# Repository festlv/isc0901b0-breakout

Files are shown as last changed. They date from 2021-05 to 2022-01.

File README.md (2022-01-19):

# ISC0901B0 breakout board

ISC0901B0 is 336x256 microbolometer LWIR sensor manufactured by FLIR. 
Apparently it is being used in Tau2/Vue series camera cores, as well as many other FLIR products. 
Autoliv NV3 is also based on this sensor, and buying a second-hand, possibly damaged Autoliv NV3 module is probably the cheapest way to obtain such a sensor.

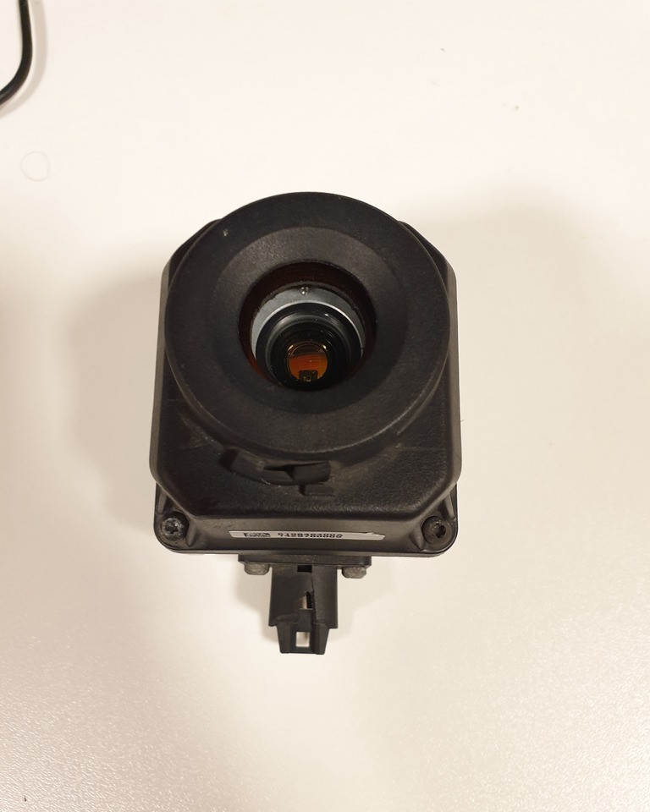
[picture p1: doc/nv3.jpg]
Autoliv NV3 front

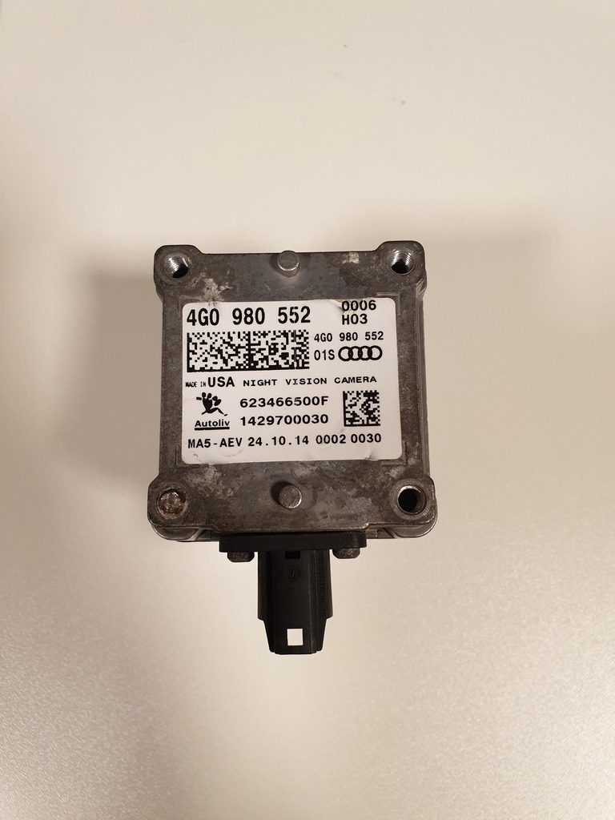
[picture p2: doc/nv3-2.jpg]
Autoliv NV3 back


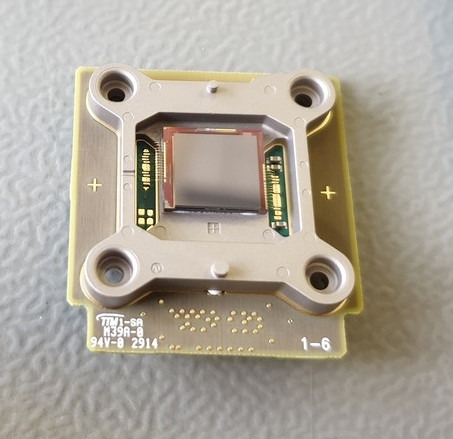
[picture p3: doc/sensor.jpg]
sensor

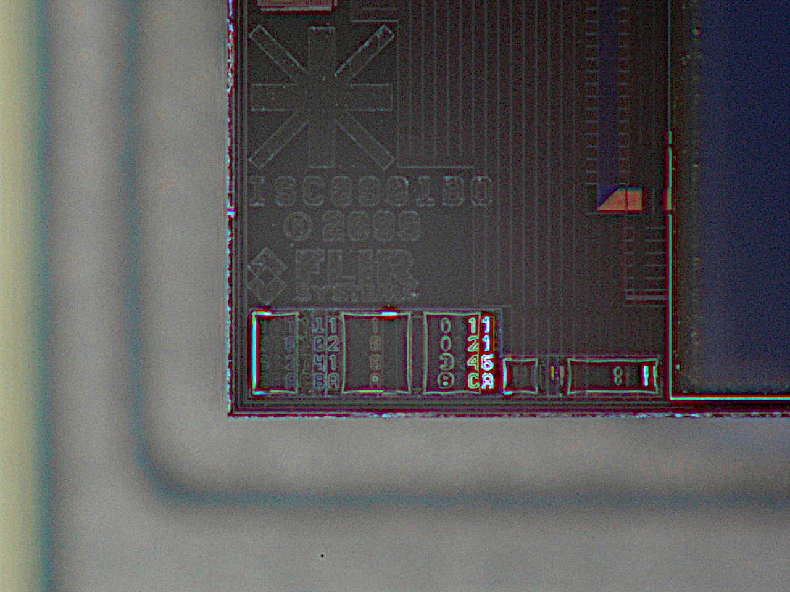
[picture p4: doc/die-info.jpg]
sensor-die

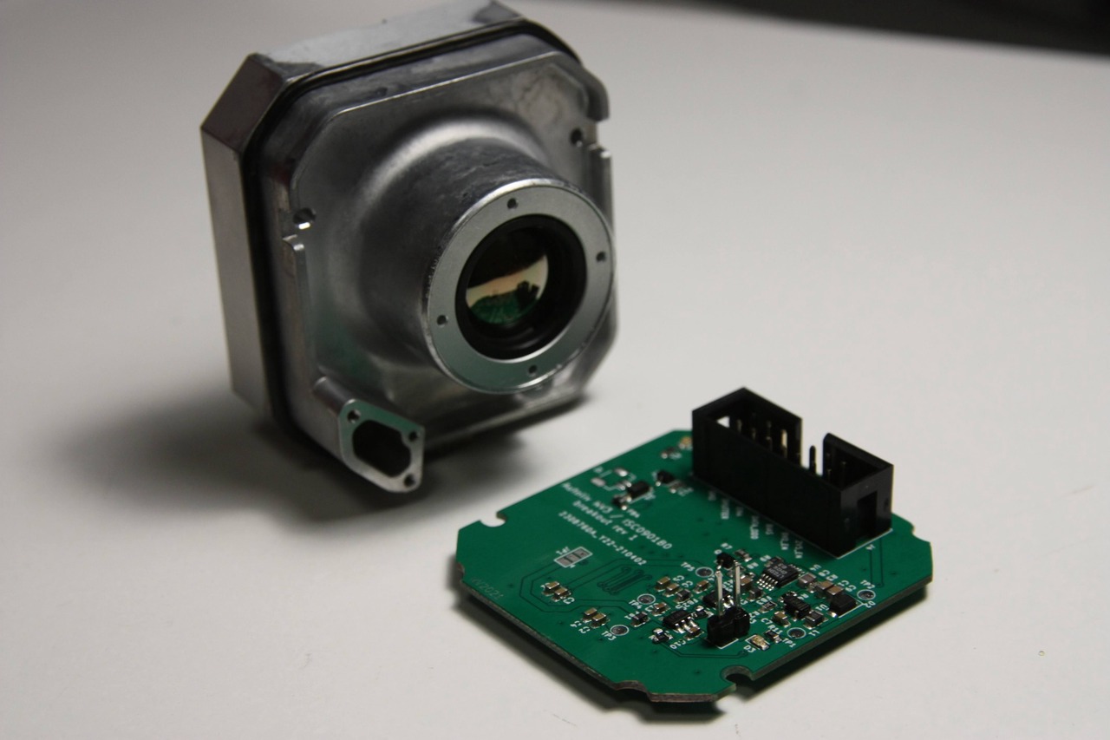
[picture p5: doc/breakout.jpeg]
breakout board


This breakout board connects directly to sensor and provides all the neccessary signals on 14-pin 2.54mm pin header (or IDC header).
It also generates the three required power rails: 2.5V for IO signals, 3.3V for core power and switchable 9/11V bias voltage.
Breakout board input voltage: 5V.
Sensor power consumption (incl. Iq of step-up convertor and LDO losses): approx 60-65mA at 5V input to breakout board.

# Sensor physical interface

All the signals described below are single ended, at VCC_IO of the sensor (2.5V in the Autoliv NV3).

**-> CLK:** clock for the sensor (nominal 73.636MHz for 60Hz). Sampling at other frequencies works, but the image is over/under exposed, as the CMD presumably configures the sensor for particular integration time.

**-> CMD:** synchronous command to sensor (output on rising edge). Bit order: MSB first. 

**-> BIAS:** synchronous bias data value to sensor. Each bias value is 7-bits long, so there is a value for each pixel. Bit order: LSB first

**-> ENA:** enable signal to sensor (?). High = sensor enabled, low = sensor disabled.

**<- DATA_0, DATA_1:** two data bits from sensor (output on falling edge, presumably sampled on rising). Each of the data lines represents a separate pixel. Bit order: LSB first.

# Startup sequence of Autoliv NV3

Measured without sensor:

1. all outputs low
2. start clk
3. 500uS delay
4. enable VCC_CORE (3.3V)
5. 15ms delay
6. enable VCC_IO (2.5V)
7. 4ms delay
8. enable VCC_BIAS (11.0V)

BIAS voltage at turn on = 11.0V

# Logical interface

After powerup sequence is finished, sensor needs to be enabled. 
Frame acquisition starts by sending a command preamble that consists of two bytes: [0x3f, 0xc0]. After that, a 20 byte sequence, of which several bytes seem to be specific to each sensor are sent.
After predetermined number of clock cycles, sensor starts responding with preamble 0x1555 on both data lines (repeating pattern of zeroes and ones).

One cycle after the sensor has started responding with preamble, bias values should be sent to sensor on the bias line: one 7-bit value for every pixel. The values are specific to each sensor: if a fixed value is sent, part of the pixels may appear to be non-responsive.
After preamble (two pixels), sensor sends the subsequent 336 pixels of image data. There is a horizontal blanking period after each line.
At the end of the readout (~256 lines), command must be sent again to initate sensor response.

The specific values for command and bias values appear to be stored in the encrypted regions of flash memory on Autoliv NV3. Further research is needed to determine if it's feasible to come up with
these values without access to flash memory contents of Autoliv NV3.

## Version history
* rev1 of this breakout board has been verified on Audi 4G0980552. 
  Observed issues: 
  * even with disabled boost converter, current path was provided by inductor.
  * outline of the PCB was slightly too large and did not fit the enclosure.
  * the 2.54mm header with just a single ground pin was very poor choice for an interface that runs at ~73MHz. It does work with ~5cm long cable though, but it's recommended to change to a different connector and add several more ground pins.

* rev2: fix first 2 problems mentioned above
* rev3: Changed the 2.54mm header with 20pin 0.5mm pitch FPC connector for better signal integrity.

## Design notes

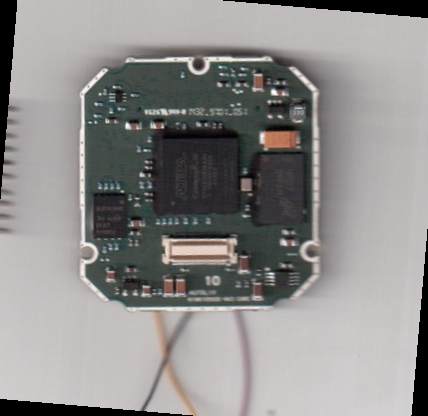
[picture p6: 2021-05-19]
pcb-outline.png

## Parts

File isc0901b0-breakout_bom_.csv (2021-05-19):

Component | Description | Part | References | Value | Footprint | Quantity Per PCB | Datasheet | MPN | Manufacturer | Config
1 | Unpolarized capacitor, small symbol | C_Small | C8 | 10pF | C_0603_1608Metric | 1 | ~
2 | Unpolarized capacitor, small symbol | C_Small | C10 C11 C13 C14 | 1uF | C_0603_1608Metric | 4 | ~
3 | Unpolarized capacitor, small symbol | C_Small | C3 C4 C6 | 0.1uF x 50V | C_0603_1608Metric | 3 | ~
4 | Unpolarized capacitor, small symbol | C_Small | C1 C2 C5 C7 C9 C12 C15 | 10uF x 25V | C_0603_1608Metric | 7 | ~ | GRT188R61E106ME13D | Murata
5 | Light emitting diode, small symbol | LED_Small | D1 D3 | LED_RED | D_0603_1608Metric | 2 | ~
6 | Diode, small symbol | D_Small | D2 D4 | MBR0520LT1 | D_SOD-123 | 2 | ~ | MBR0520LT1
7 | Ferrite bead, small symbol | Ferrite_Bead_Small | FB1 FB2 FB3 FB4 | 200R | L_0603_1608Metric | 4 | ~
8 | Generic connectable mounting pin connector, double row, 02x20, counter clockwise pin numbering scheme (similar to DIP packge numbering), script generated (kicad-library-utils/schlib/autogen/connector/) | Conn_02x20_Counter_Clockwise_MountingPin | J2 | 52991-0408 | 52991-0408 | 1 | ~ | 52991-0408
9 | Generic connector, single row, 01x02, script generated (kicad-library-utils/schlib/autogen/connector/) | Conn_01x02 | J3 | Conn_01x02 | PinHeader_1x02_P2.54mm_Vertical | 1 | ~
10 | Generic connector, single row, 01x02, script generated (kicad-library-utils/schlib/autogen/connector/) | Conn_01x02 | J5 | Conn_01x02 | JST_SH_BM02B-SRSS-TB_1x02-1MP_P1.00mm_Vertical | 1 | ~ | BM02B-SRSS-TB(LF)(SN) | JST
11 | Generic connector, double row, 02x07, odd/even pin numbering scheme (row 1 odd numbers, row 2 even numbers), script generated (kicad-library-utils/schlib/autogen/connector/) | Conn_02x07_Odd_Even | J4 | IDC_02x07 | IDC-Header_2x07_P2.54mm_Vertical | 1 | ~ | 302-S141 | On Shore Technology Inc.
12 | Inductor, small symbol | L_Small | L1 | 4.7uH | L_0805_2012Metric | 1 | ~
13 | N-MOSFET transistor, gate/source/drain | Q_NMOS_GSD | Q1 Q2 | BSS138PW,115 | SOT-323_SC-70 | 2 | ~ | BSS138PW,115
14 | Resistor, small symbol | R_Small | R1 R11 | 1K | R_0603_1608Metric | 2 | ~
15 | Resistor, small symbol | R_Small | R2 R7 R12 | 10K | R_0603_1608Metric | 3 | ~
16 | Resistor, small symbol | R_Small | R4 | 11.5K | R_0603_1608Metric | 1 | ~
17 | Resistor, small symbol | R_Small | R3 | 100K | R_0603_1608Metric | 1 | ~
18 | Resistor, small symbol | R_Small | R10 | 110K | R_0603_1608Metric | 1 | ~
19 | Resistor, small symbol | R_Small | R8 | 499K | R_0603_1608Metric | 1 | ~
20 | 4 resistor network, parallel topology | R_Pack04 | RN1 RN2 RN3 | 22R | R_Array_Concave_4x0603 | 3 | ~ | EXB-V8V220JV
21 |  | ADP151 | U3 | ADP151AUJZ-2.5-R7 | TSOT-23-5 | 1 |  | ADP151AUJZ-2.5-R7
22 |  | ADP151 | U2 | ADP151AUJZ-3.3-R7 | TSOT-23-5 | 1 |  | ADP151AUJZ-3.3-R7
23 | 200mA, Adjustable, Ultralow Noise, Ultrahigh PSRR RF Linear Regulator, MSOP-10 | LT3042xMSE | U4 | LT3042xMSE | MSOP-10-1EP_3x3mm_P0.5mm_EP1.68x1.88mm | 1 | https://www.analog.com/media/en/technical-documentation/data-sheets/3042fb.pdf | LT3042EMSE#PBF
24 | Synchronous Boost Regulator, Adjustable Output up to 28V, 250 mA Switch Current Limit, SOT-23-5 | TPS61041DBV | U1 | TPS61041DBV | SOT-23-5 | 1 | http://www.ti.com/lit/ds/symlink/tps61040.pdf | TPS61041DBV
Component Groups: | 26
Component Count: | 50
Fitted Components: | 46
Number of PCBs: | 1
Total components: | 46
Schematic Version:
Schematic Date:
PCB Variant: | ['default']
BoM Date: | pirmdiena, 2021. gada 19. aprīlis, 15:43:23
Schematic Source: | ics0901b0-breakout.sch
KiCad Version: | Eeschema 5.1.9-73d0e3b20d~88~ubuntu20.04.1

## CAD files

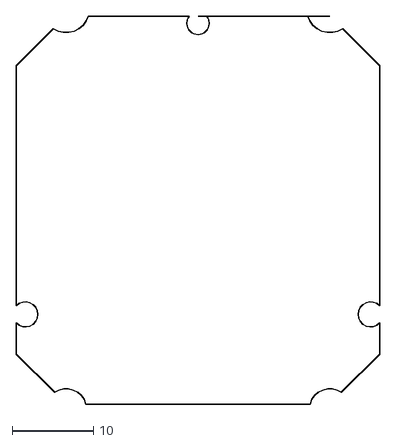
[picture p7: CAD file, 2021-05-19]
pcb-outline (1).dxf
44.9 x 47.9

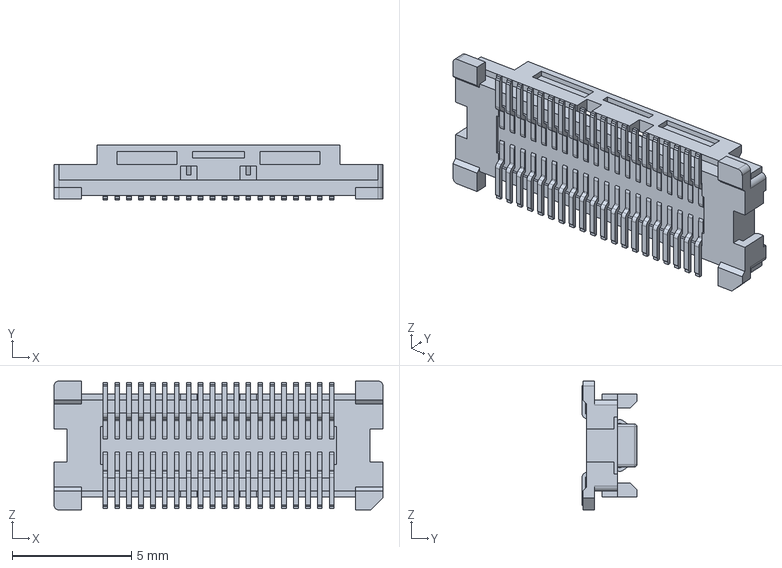
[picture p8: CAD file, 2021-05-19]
529910408.stp
13.8 x 2.30 x 5.40 mm

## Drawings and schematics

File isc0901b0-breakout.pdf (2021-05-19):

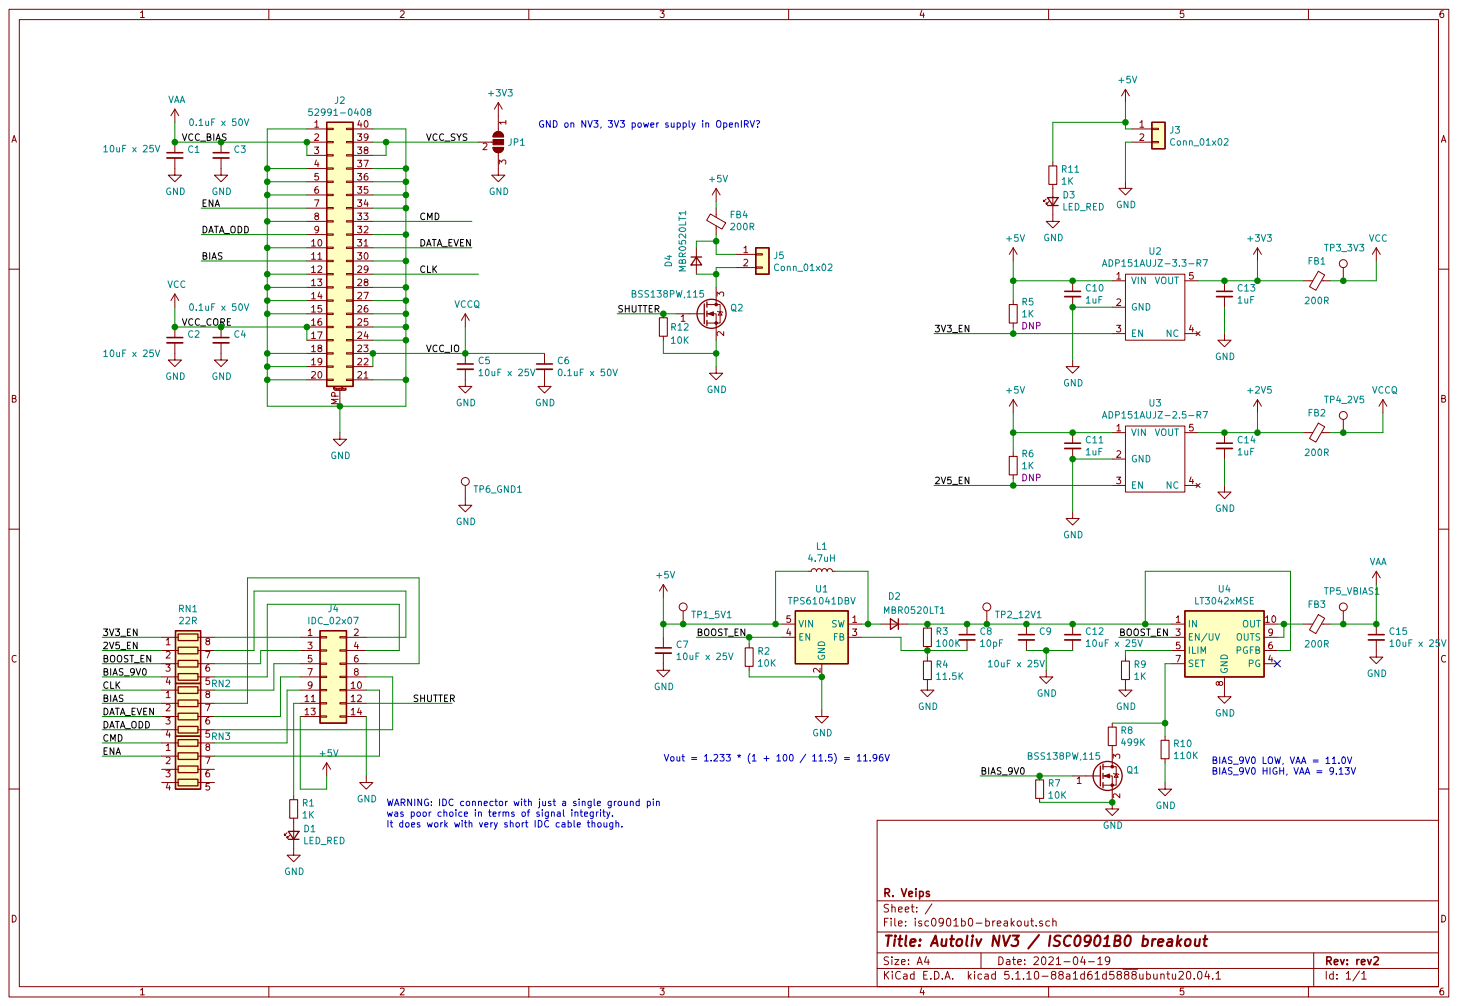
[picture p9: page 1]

GND on NV3, 3V3 power supply in OpenIRV?

5 | 36
6 | 35
7 | 34
8 | 33 32

14 | 27
15 | 26
16 | 25
17 | 24

19 | 22
20 | 21

BOOST_EN | BOOST_EN

9 | | 10
11 | | 12 14

was poor choice in terms of signal integrity.
It does work with very short IDC cable though.

Id: 1/1 Title: Autoliv NV3 / ISC0901B0 breakout File: isc0901b0-breakout.sch Sheet: / R. Veips

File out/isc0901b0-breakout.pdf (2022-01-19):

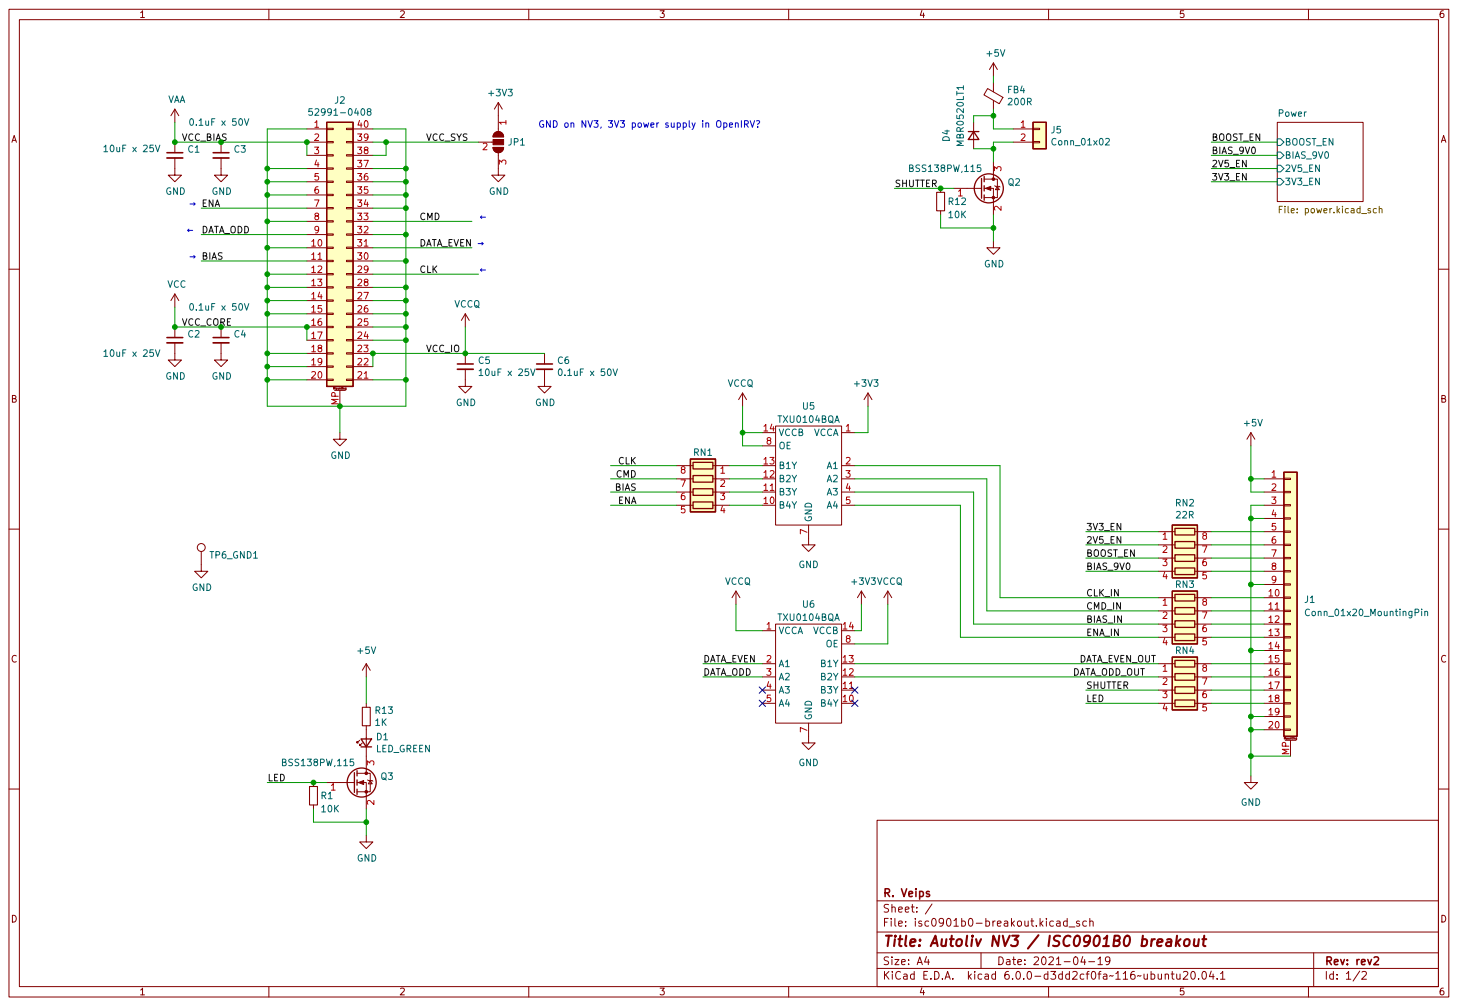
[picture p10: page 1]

8 | Mounting 1 | 33 32

GND on NV3, 3V3 power supply in OpenIRV?

5 | | 36
6 | | 35
7 | | 34

14 | 27
15 | 26
16 | 25
17 | 24

19 | 22
20 | 21

1 DATA_ODD_OUT | | 16 | J1Conn_01x20_MountingPin GND

2 SHUTTER | 7 | 17

File: isc0901b0-breakout.kicad_sch Sheet: / R. Veips

Id: 1/2 Title: Autoliv NV3 / ISC0901B0 breakout

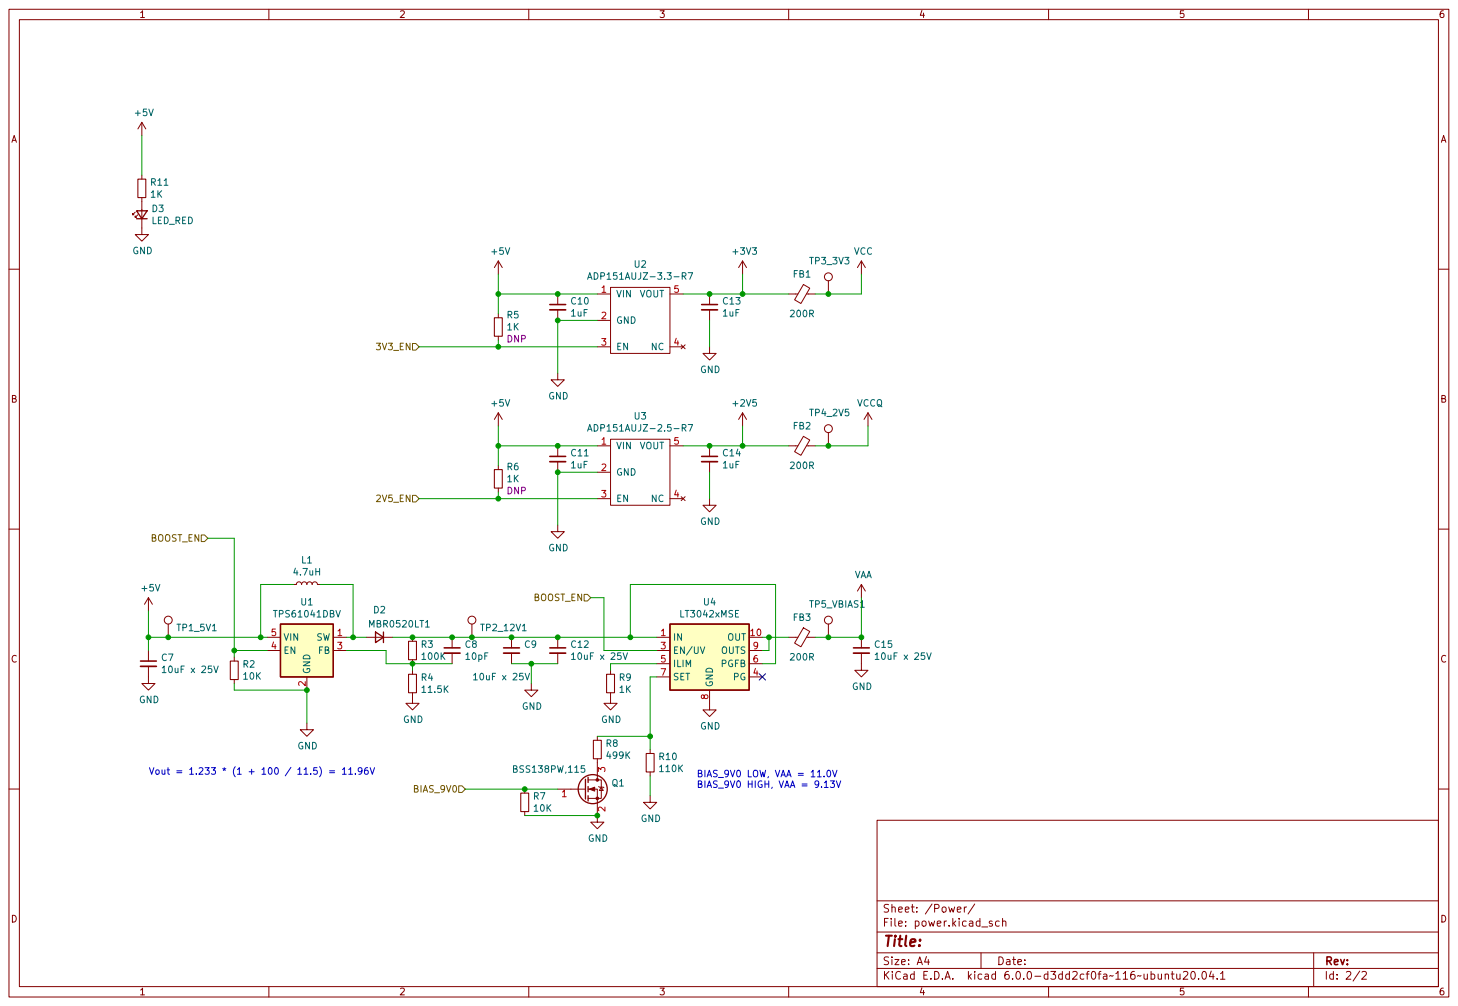
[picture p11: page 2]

File: power.kicad_sch Sheet: /Power/
Id: 2/2 Title:

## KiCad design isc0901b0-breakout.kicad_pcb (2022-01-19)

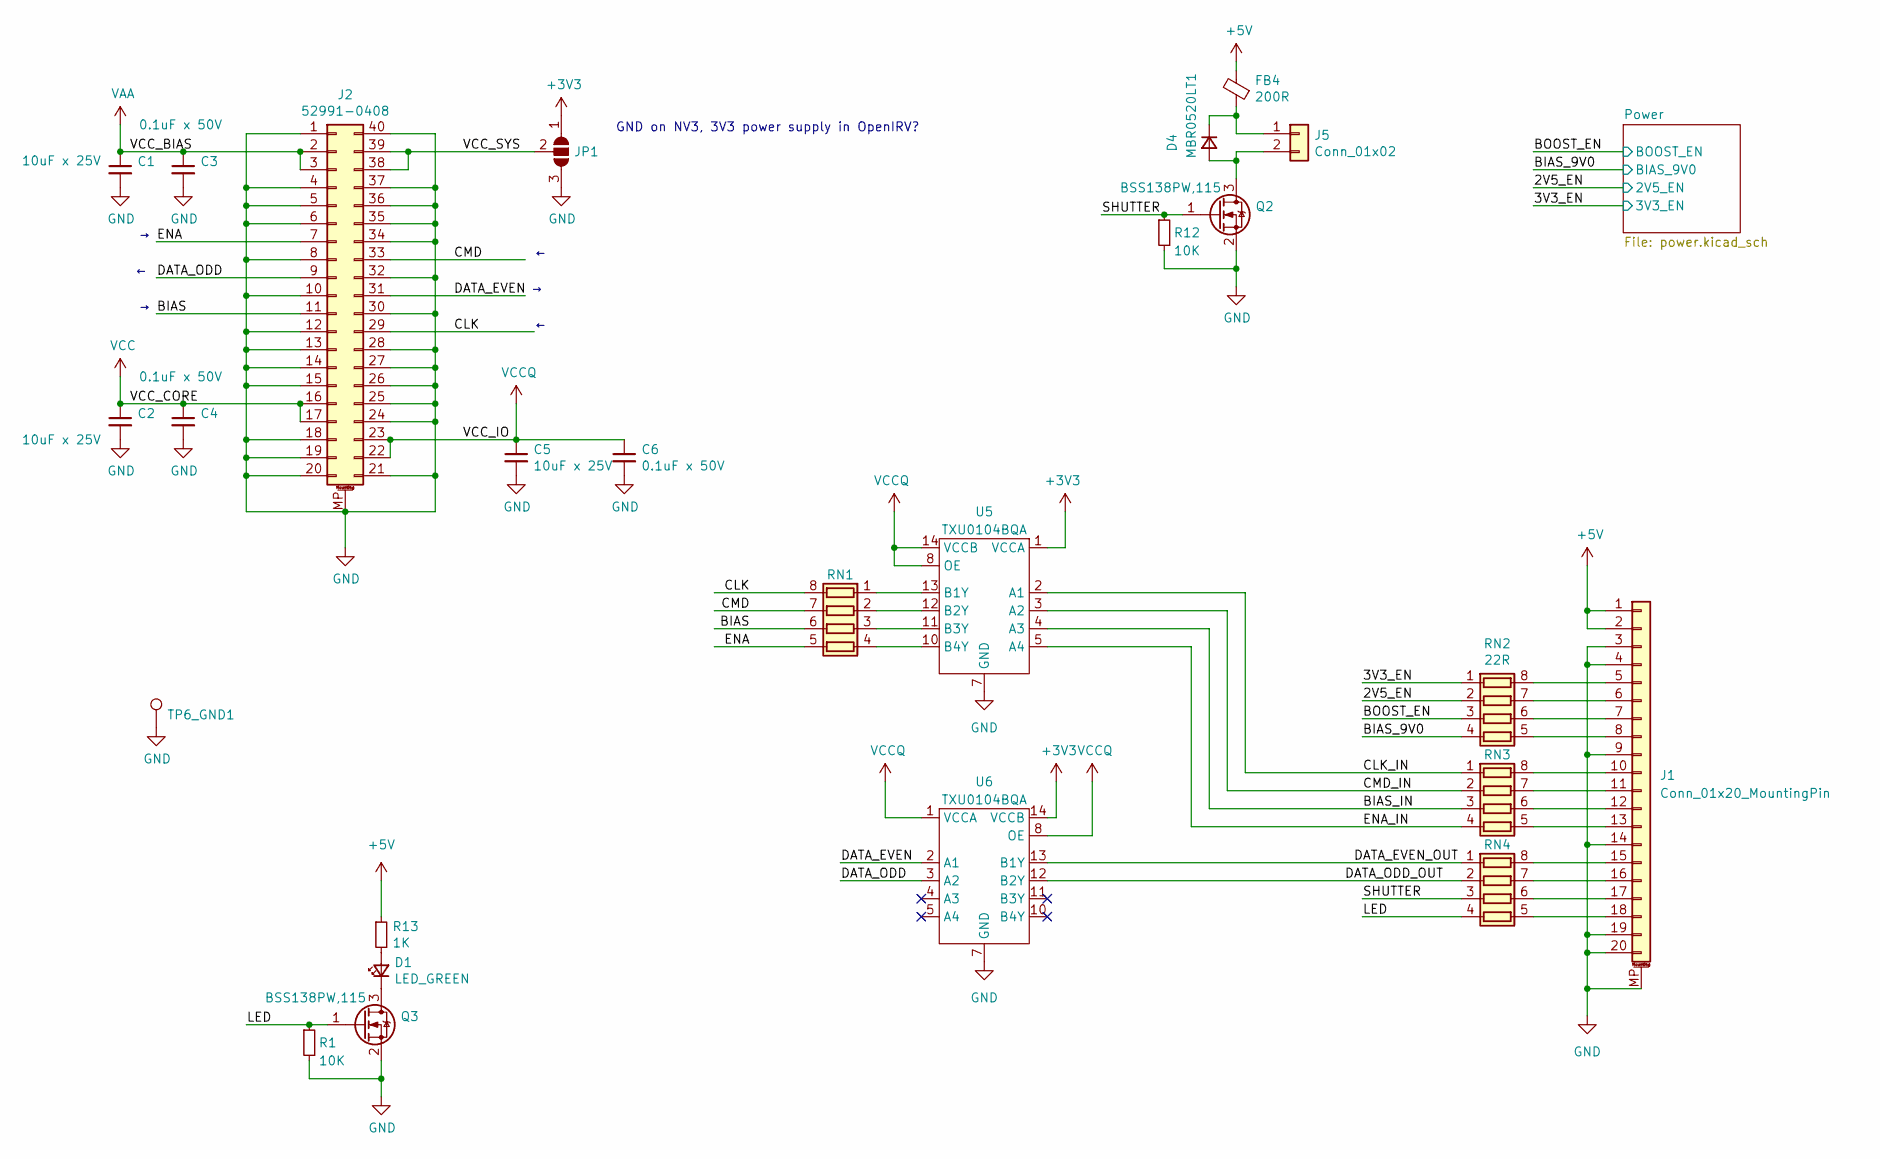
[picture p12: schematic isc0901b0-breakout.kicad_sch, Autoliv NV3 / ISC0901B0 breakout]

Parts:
C1, C2, C5: 10uF x 25V; C_0603_1608Metric; MPN GRT188R61E106ME13D
C3, C4, C6: 0.1uF x 50V; C_0603_1608Metric
D1: LED_GREEN; D_0603_1608Metric
D4: MBR0520LT1; D_SOD-123; MPN MBR0520LT1
FB4: 200R; L_0603_1608Metric
J1: Conn_01x20_MountingPin; X05C2020TZ; MPN X05C2020TZ
J2: 52991-0408; MPN 52991-0408
J5: Conn_01x02; JST_SH_BM02B-SRSS-TB_1x02-1MP_P1.00mm_Vertical; MPN BM02B-SRSS-TB(LF)(SN)
JP1: SolderJumper_3_Open; SolderJumper-3_P1.3mm_Open_Pad1.0x1.5mm
Q2, Q3: BSS138PW,115; SOT-323_SC-70; MPN BSS138PW,115
R1, R12: 10K; R_0603_1608Metric
R13: 1K; R_0603_1608Metric
RN1, RN2, RN3, RN4: 22R; R_Array_Concave_4x0603; MPN EXB-V8V220JV
TP6_GND1: TestPoint; TestPoint_Pad_D1.5mm
U5, U6: TXU0104BQA; TI_WFNQ-14_BQA; MPN TXU0104BQAR

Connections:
+3V3: JP1.1 (A), U5.1 (VCCA), U6.14 (VCCB); also elsewhere on the board
+5V: FB4.2, J1.1, J1.2, R13.1; also elsewhere on the board
/2V5_EN: RN2.2 (R2.1); also elsewhere on the board
/3V3_EN: RN2.1 (R1.1); also elsewhere on the board
/BIAS: J2.11, RN1.6 (R3.2)
/BIAS_9V0: RN2.4 (R4.1); also elsewhere on the board
/BIAS_IN: RN3.3 (R3.1), U5.4 (A3)
/BOOST_EN: RN2.3 (R3.1); also elsewhere on the board
/CLK: J2.29, RN1.8 (R1.2)
/CLK_IN: RN3.1 (R1.1), U5.2 (A1)
/CMD: J2.33, RN1.7 (R2.2)
/CMD_IN: RN3.2 (R2.1), U5.3 (A2)
/DATA_EVEN: J2.31, U6.2 (A1)
/DATA_EVEN_OUT: RN4.1 (R1.1), U6.13 (B1Y)
/DATA_ODD: J2.9, U6.3 (A2)
/DATA_ODD_OUT: RN4.2 (R2.1), U6.12 (B2Y)
/ENA: J2.7, RN1.5 (R4.2)
/ENA_IN: RN3.4 (R4.1), U5.5 (A4)
/LED: Q3.1 (G), R1.1, RN4.4 (R4.1)
/SHUTTER: Q2.1 (G), R12.1, RN4.3 (R3.1)
/VCC_SYS: J2.38, J2.39, JP1.2 (C)
GND: C1.2, C2.2, C3.2, C4.2, C5.2, C6.2, J1.3, J1.4, J1.9, J1.14, J1.19, J1.20, J1.MP (MountPin), J2.1, J2.4, J2.5, J2.6, J2.8, J2.10, J2.12, J2.13, J2.14, J2.15, J2.18, J2.19, J2.20, J2.21, J2.24, J2.25, J2.26, J2.27, J2.28, J2.30, J2.32, J2.34, J2.35, J2.36, J2.37, J2.40, J2.MP (MountPin), JP1.3 (B), Q2.2 (S), Q3.2 (S), R1.2, R12.2, TP6_GND1.1, U5.7 (GND), U6.7 (GND); also elsewhere on the board
unnamed: D1.1 (K), Q3.3 (D)
unnamed: D1.2 (A), R13.2
unnamed: D4.1 (K), FB4.1, J5.1
unnamed: D4.2 (A), J5.2, Q2.3 (D)
unnamed: J1.5, RN2.8 (R1.2)
unnamed: J1.6, RN2.7 (R2.2)
unnamed: J1.7, RN2.6 (R3.2)
unnamed: J1.8, RN2.5 (R4.2)
unnamed: J1.10, RN3.8 (R1.2)
unnamed: J1.11, RN3.7 (R2.2)
unnamed: J1.12, RN3.6 (R3.2)
unnamed: J1.13, RN3.5 (R4.2)
unnamed: J1.15, RN4.8 (R1.2)
unnamed: J1.16, RN4.7 (R2.2)
unnamed: J1.17, RN4.6 (R3.2)
unnamed: J1.18, RN4.5 (R4.2)
unnamed: RN1.1 (R1.1), U5.13 (B1Y)
unnamed: RN1.2 (R2.1), U5.12 (B2Y)
unnamed: RN1.3 (R3.1), U5.11 (B3Y)
unnamed: RN1.4 (R4.1), U5.10 (B4Y)
VAA: C1.1, C3.1, J2.2, J2.3; also elsewhere on the board
VCC: C2.1, C4.1, J2.16, J2.17; also elsewhere on the board
VCCQ: C5.1, C6.1, J2.22, J2.23, U5.8 (OE), U5.14 (VCCB), U6.1 (VCCA), U6.8 (OE); also elsewhere on the board

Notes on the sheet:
GND on NV3, 3V3 power supply in OpenIRV?

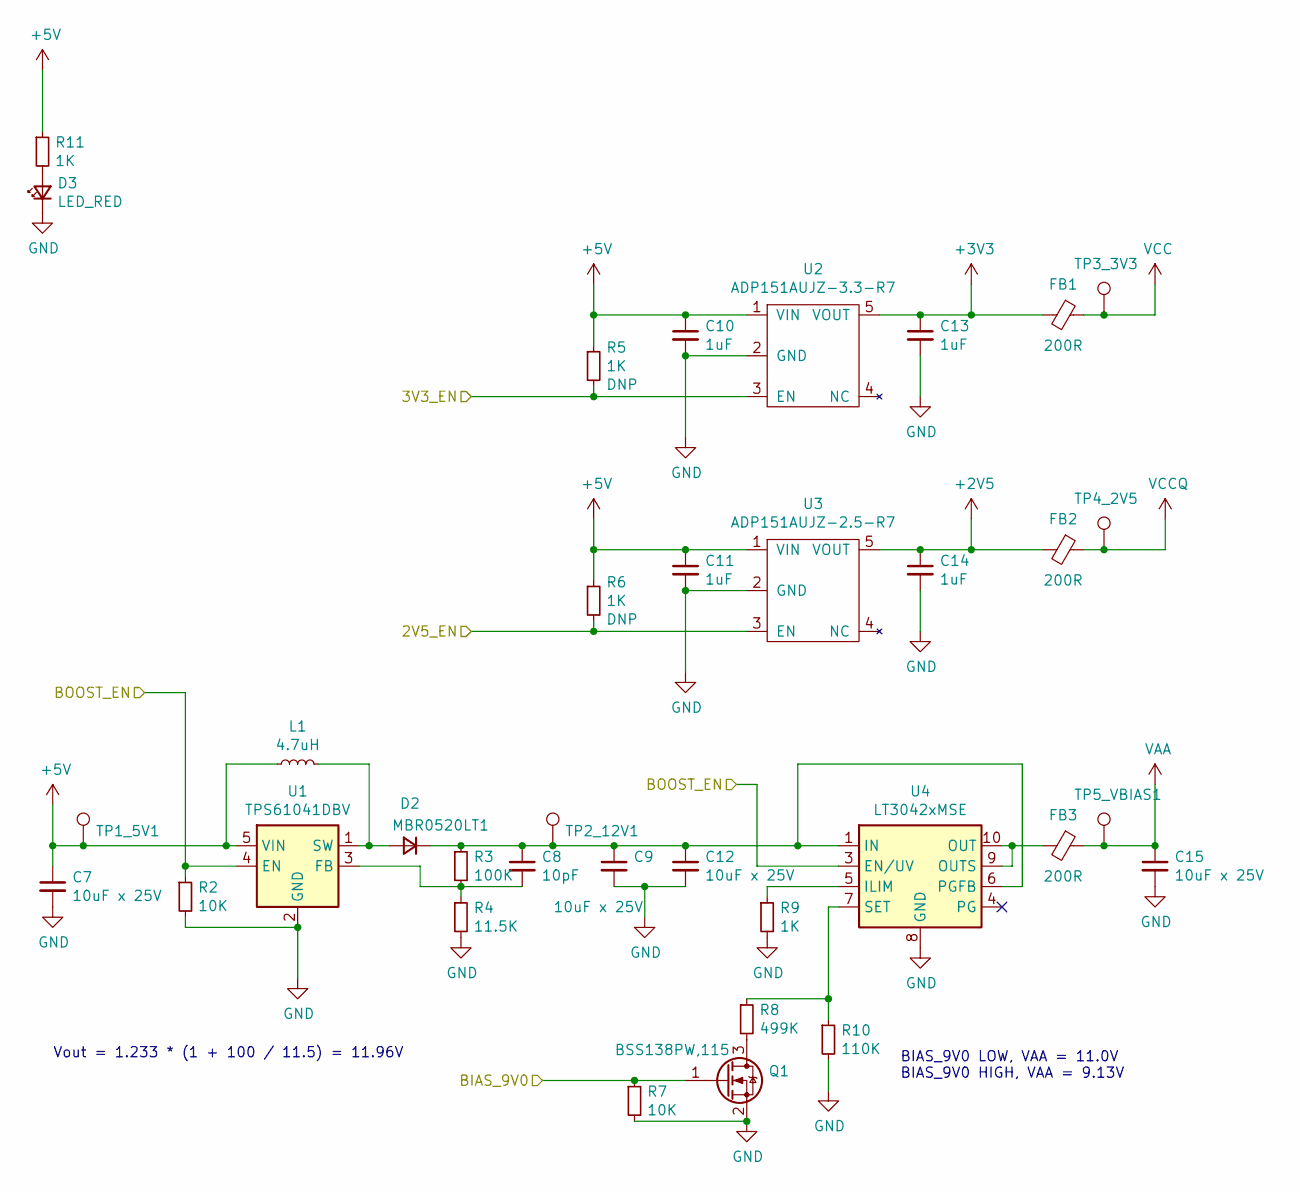
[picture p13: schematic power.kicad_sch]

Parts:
C7, C9, C12, C15: 10uF x 25V; C_0603_1608Metric; MPN GRT188R61E106ME13D
C8: 10pF; C_0603_1608Metric
C10, C11, C13, C14: 1uF; C_0603_1608Metric
D2: MBR0520LT1; D_SOD-123
D3: LED_RED; D_0603_1608Metric
FB1, FB2, FB3: 200R; L_0603_1608Metric
L1: 4.7uH; L_0805_2012Metric
Q1: BSS138PW,115; SOT-323_SC-70; MPN BSS138PW,115
R2, R7: 10K; R_0603_1608Metric
R3: 100K; R_0603_1608Metric
R4: 11.5K; R_0603_1608Metric
R5, R6, R9, R11: 1K; R_0603_1608Metric
R8: 499K; R_0603_1608Metric
R10: 110K; R_0603_1608Metric
TP1_5V1, TP2_12V1, TP3_3V3, TP4_2V5, TP5_VBIAS1: TestPoint; TestPoint_Pad_D1.5mm
U1: TPS61041DBV; SOT-23-5; MPN TPS61041DBV
U2: ADP151AUJZ-3.3-R7; TSOT-23-5; MPN ADP151AUJZ-3.3-R7
U3: ADP151AUJZ-2.5-R7; TSOT-23-5; MPN ADP151AUJZ-2.5-R7
U4: LT3042xMSE; MSOP-10-1EP_3x3mm_P0.5mm_EP1.68x1.88mm; MPN LT3042EMSE#PBF

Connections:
+2V5: C14.1, FB2.2, U3.5 (VOUT)
+3V3: C13.1, FB1.2, U2.5 (VOUT); also elsewhere on the board
+5V: C7.1, C10.1, C11.1, L1.1, R5.1, R6.1, R11.1, TP1_5V1.1, U1.5 (VIN), U2.1 (VIN), U3.1 (VIN); also elsewhere on the board
/2V5_EN: R6.2, U3.3 (EN); also elsewhere on the board
/3V3_EN: R5.2, U2.3 (EN); also elsewhere on the board
/BIAS_9V0: Q1.1 (G), R7.1; also elsewhere on the board
/BOOST_EN: R2.1, U1.4 (EN), U4.3 (EN/UV); also elsewhere on the board
GND: C7.2, C9.2, C10.2, C11.2, C12.2, C13.2, C14.2, C15.2, D3.1 (K), Q1.2 (S), R2.2, R4.2, R7.2, R9.2, R10.2, U1.2 (GND), U2.2 (GND), U3.2 (GND), U4.8 (GND), U4.11 (GND); also elsewhere on the board
unnamed: C8.2, R3.2, R4.1, U1.3 (FB)
unnamed: C8.1, C9.1, C12.1, D2.1 (K), R3.1, TP2_12V1.1, U4.1 (IN), U4.2 (IN), U4.6 (PGFB)
unnamed: D2.2 (A), L1.2, U1.1 (SW)
unnamed: D3.2 (A), R11.2
unnamed: FB3.2, U4.9 (OUTS), U4.10 (OUT)
unnamed: Q1.3 (D), R8.2
unnamed: R9.1, U4.5 (ILIM)
unnamed: R8.1, R10.1, U4.7 (SET)
VAA: C15.1, FB3.1, TP5_VBIAS1.1; also elsewhere on the board
VCC: FB1.1, TP3_3V3.1; also elsewhere on the board
VCCQ: FB2.1, TP4_2V5.1; also elsewhere on the board

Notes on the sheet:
BIAS_9V0 LOW, VAA = 11.0V BIAS_9V0 HIGH, VAA = 9.13V
Vout = 1.233 * (1 + 100 / 11.5) = 11.96V

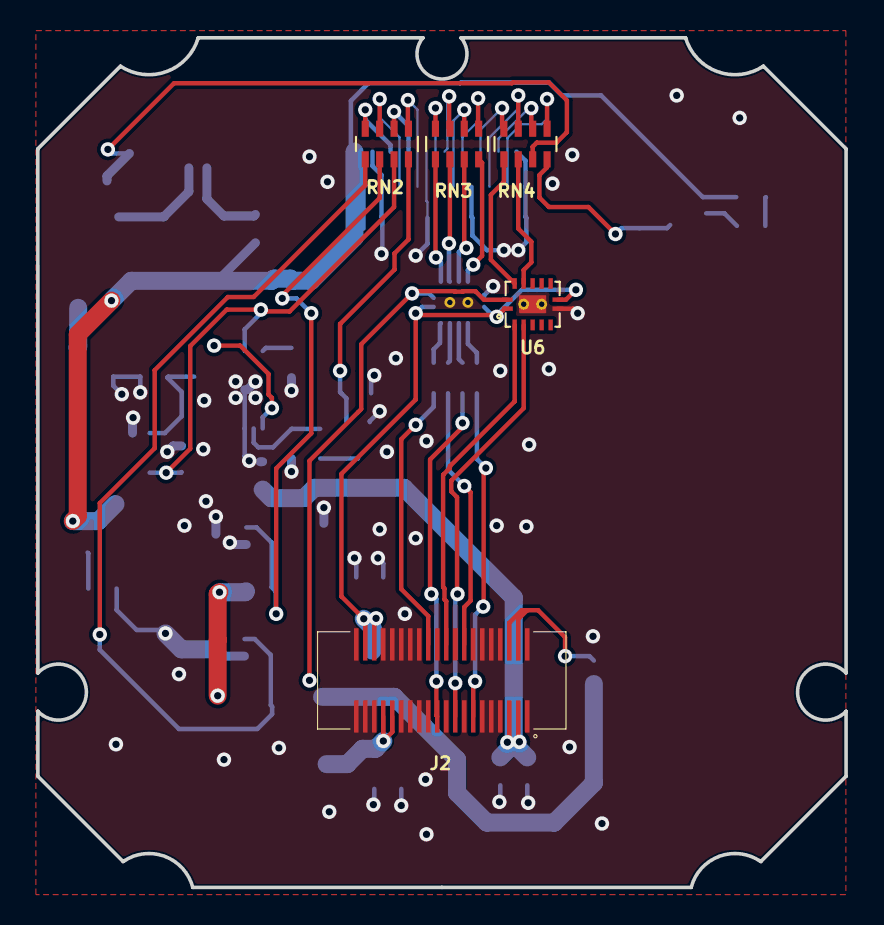
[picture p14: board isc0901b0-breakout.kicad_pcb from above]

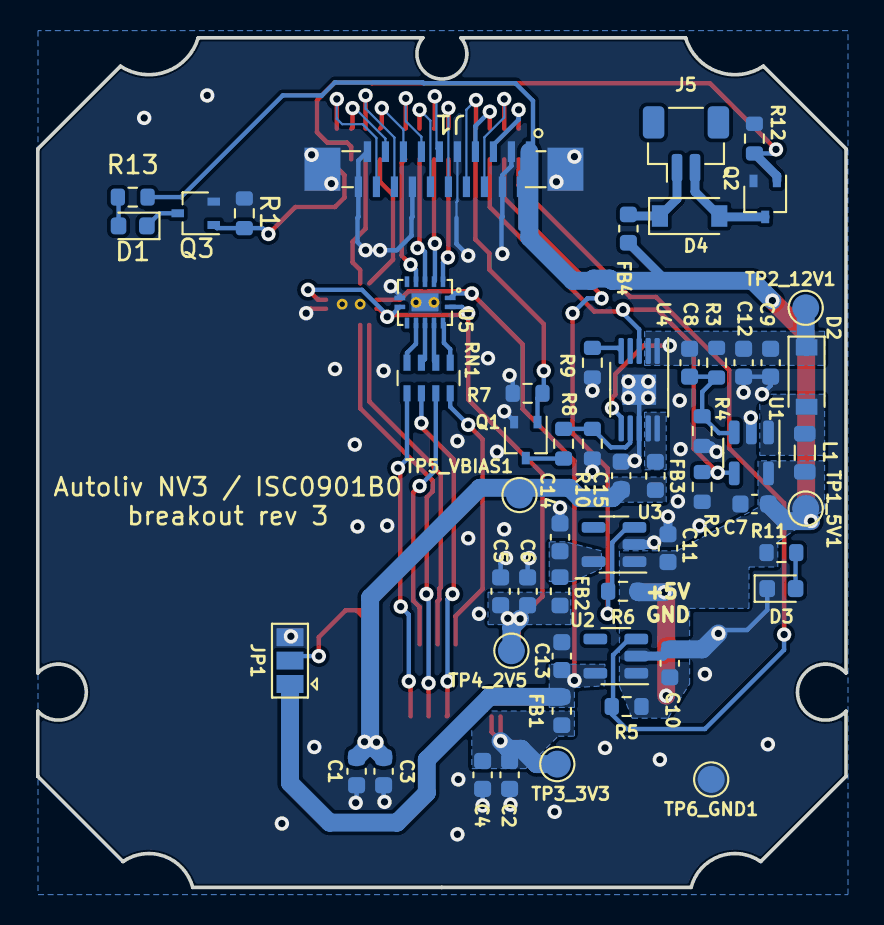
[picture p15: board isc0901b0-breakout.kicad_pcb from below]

Board: 2 copper layers, 44.9 x 47.2 mm, 60 parts (55 on the bottom side), 54 nets.

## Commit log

2021-05-19 Initial commit with rev2.
    [529910408.stp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]
2021-05-19 Add information on sensor interface
2022-01-19 Finished rev3 of the board with 20pin FPC connector
    [isc0901b0-breakout-B_Cu.gbr, isc0901b0-breakout-B_Mask.gbr, isc0901b0-breakout-B_Paste.gbr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]
